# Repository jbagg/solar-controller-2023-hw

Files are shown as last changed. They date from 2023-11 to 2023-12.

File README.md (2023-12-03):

This is a differential temperature controller with 8 temperature sensor inputs, 4 digital inputs and 8 opto coupled solid state relay outputs.  The controller is compatible with the [LMT01](https://www.ti.com/product/LMT01) temperature sensor.  Each temperature sensor is connected to the controller with one pair of a cat 5 or 6 cable.  The temperature sensor uses the same 2 wires for both power and signaling.  Each temperature sensor has a max length of 45 meters.

The LMT01 is an ideal temperature sensor for differential temperature controllers as it

* uses digital signaling so no noise is added to the measurement over the cable back to the controller.
* allows for differential signaling for long cables.
* needs only 2 wires (twisted pair) per sensor.  Power and signaling is done over the same wires.

### Sensor Operation

The LMT01 uses a Pulse Train Interface to communicate the temperature where the number of output pulses is proportional to temperature.  The 1 or 0, high or low of each pulse is communicated by switching the device current consumption between two values, aprox 34uA and 125uA.

The controller measures each LMT01 sensor one at a time via U1, ADG707 differential 8-to-1 multiplexer.  When a sensor is muxed, its positive pin is connected to a 3.3kΩ pull up (R17) and its negative pin is connected to a 3.3kΩ pull down (R18).  Each resistor sees about a 300mV change in voltage between the pulse’s high / low 34uA and 125uA change in device current.  When R17’s change is positive, R18’s is negative.  These signal pulses are AC coupled to a differential op-amp circuit (U3A) via C20 and C39.  680pF was chosen to be about half the time constant for the 88Khz pulse.

1 / 88Khz = 11.4uS.  680pF * 10K = 6.8uS.

C20 and C39 must charge before they pass the pulses.  Too large a value looses pulses at the beginning.  680pF was measured to loose about 1 pulse, or about 0.1 C.

The differential op-amp circuit separates common noise from the differential signal that the twisted pair has picked up from noise sources over it’s length.  The differential op-amp circuit has gain to compensate for the signal loss in the cable.  The differential op-amp circuit has a gain of about 5 which is the max value not to saturate the strongest signal, a sensor connected directly to the controller without a length of wire.

[300mV - (-300mV)] * 5 <br>
= 600mV * 5 <br>
= 3v  (U1 has 3.3v supply)

The gain can be increased to just below the saturation point of the shortest cable.  C1 and C2 filter high frequency noise.  The output of the differential op-amp circuit is feed to a comparator with hysteresis (U3B).

The comparator has a hysteresis of 314mV.  A cat-5 twisted pair of up to 45 meters still had enough margin above the 314mV hysteresis for reliable operation.  The output of the comparator is feed to the microcontroller’s external timer counter clock input.

The microcontroller’s external timer counter clock (TCLK0) input feeds both TC0 and TC1 timer counters in the SAM4S2 mcu.  TC0 uses TCLK0 as a clock source and thus counts the pulses from the sensor.  The value of TC0 can be read and converted to a temperature.  TC1 is used to trigger when the LMT01 has finished sending pulses.  TC1 is clocked from the main mcu clock.  TC1 is configured so that its value is reset each time there is an edge on TCLK0.  TC1 compare C register is configured to a value about 2x the normal pulse period of the LMT01.  Each pulse from the LMT01 resets the count in TC1.  When the LMT01 stops sending pulses, TC1’s value grows to match compare C register which triggers an interrupt for the software to read TC0 and then change the mux to the next sensor and start all over again.

### Opto Coupler Ouptputs

Opto coupler AQH0213 is used to drive the coil of a relay that controls the load.  The AQH0213 is apart of a family of opto couplers with the same footprint.  The appropriate opto coupler can be chosen to match the voltage and current requirements of the specific relay for the application.

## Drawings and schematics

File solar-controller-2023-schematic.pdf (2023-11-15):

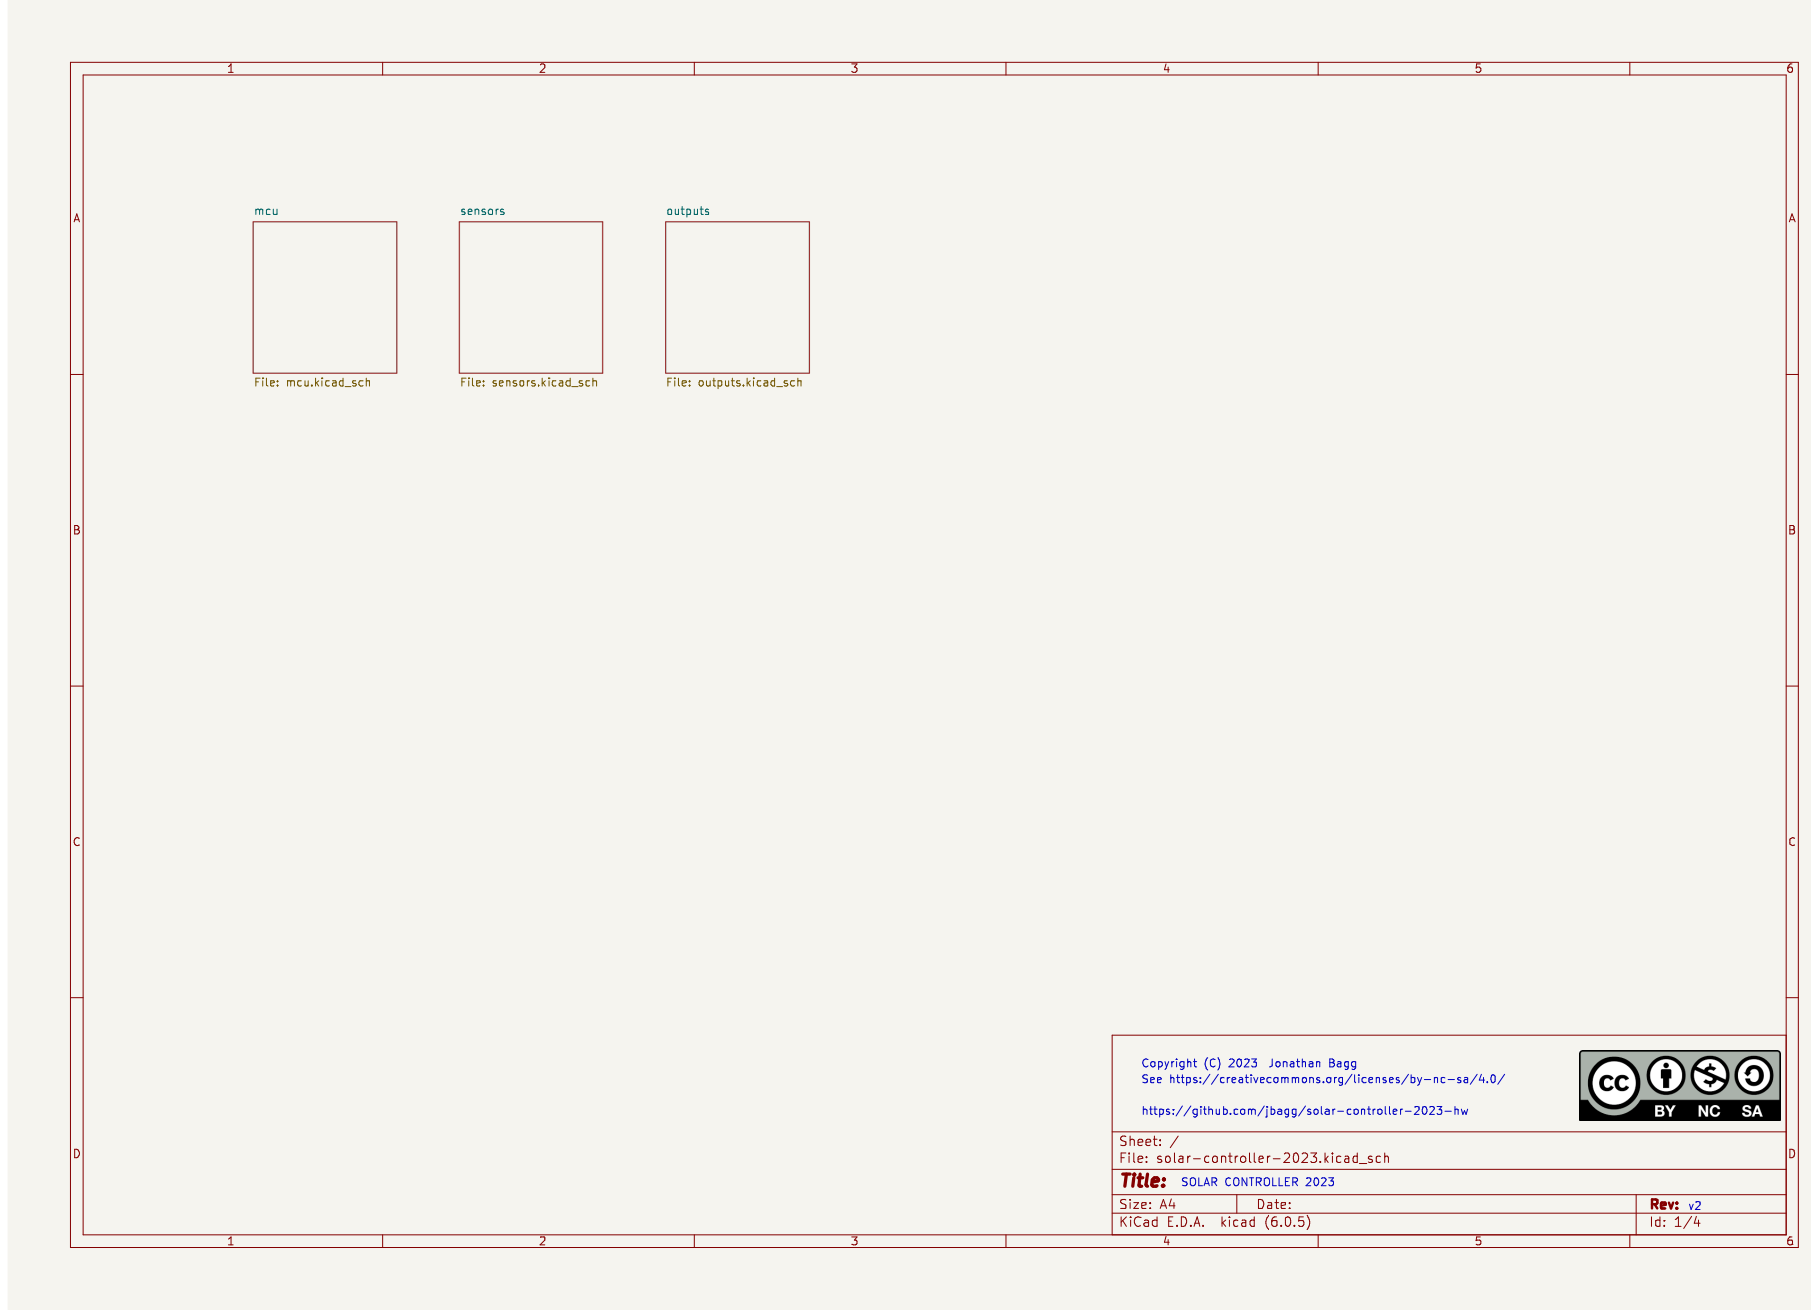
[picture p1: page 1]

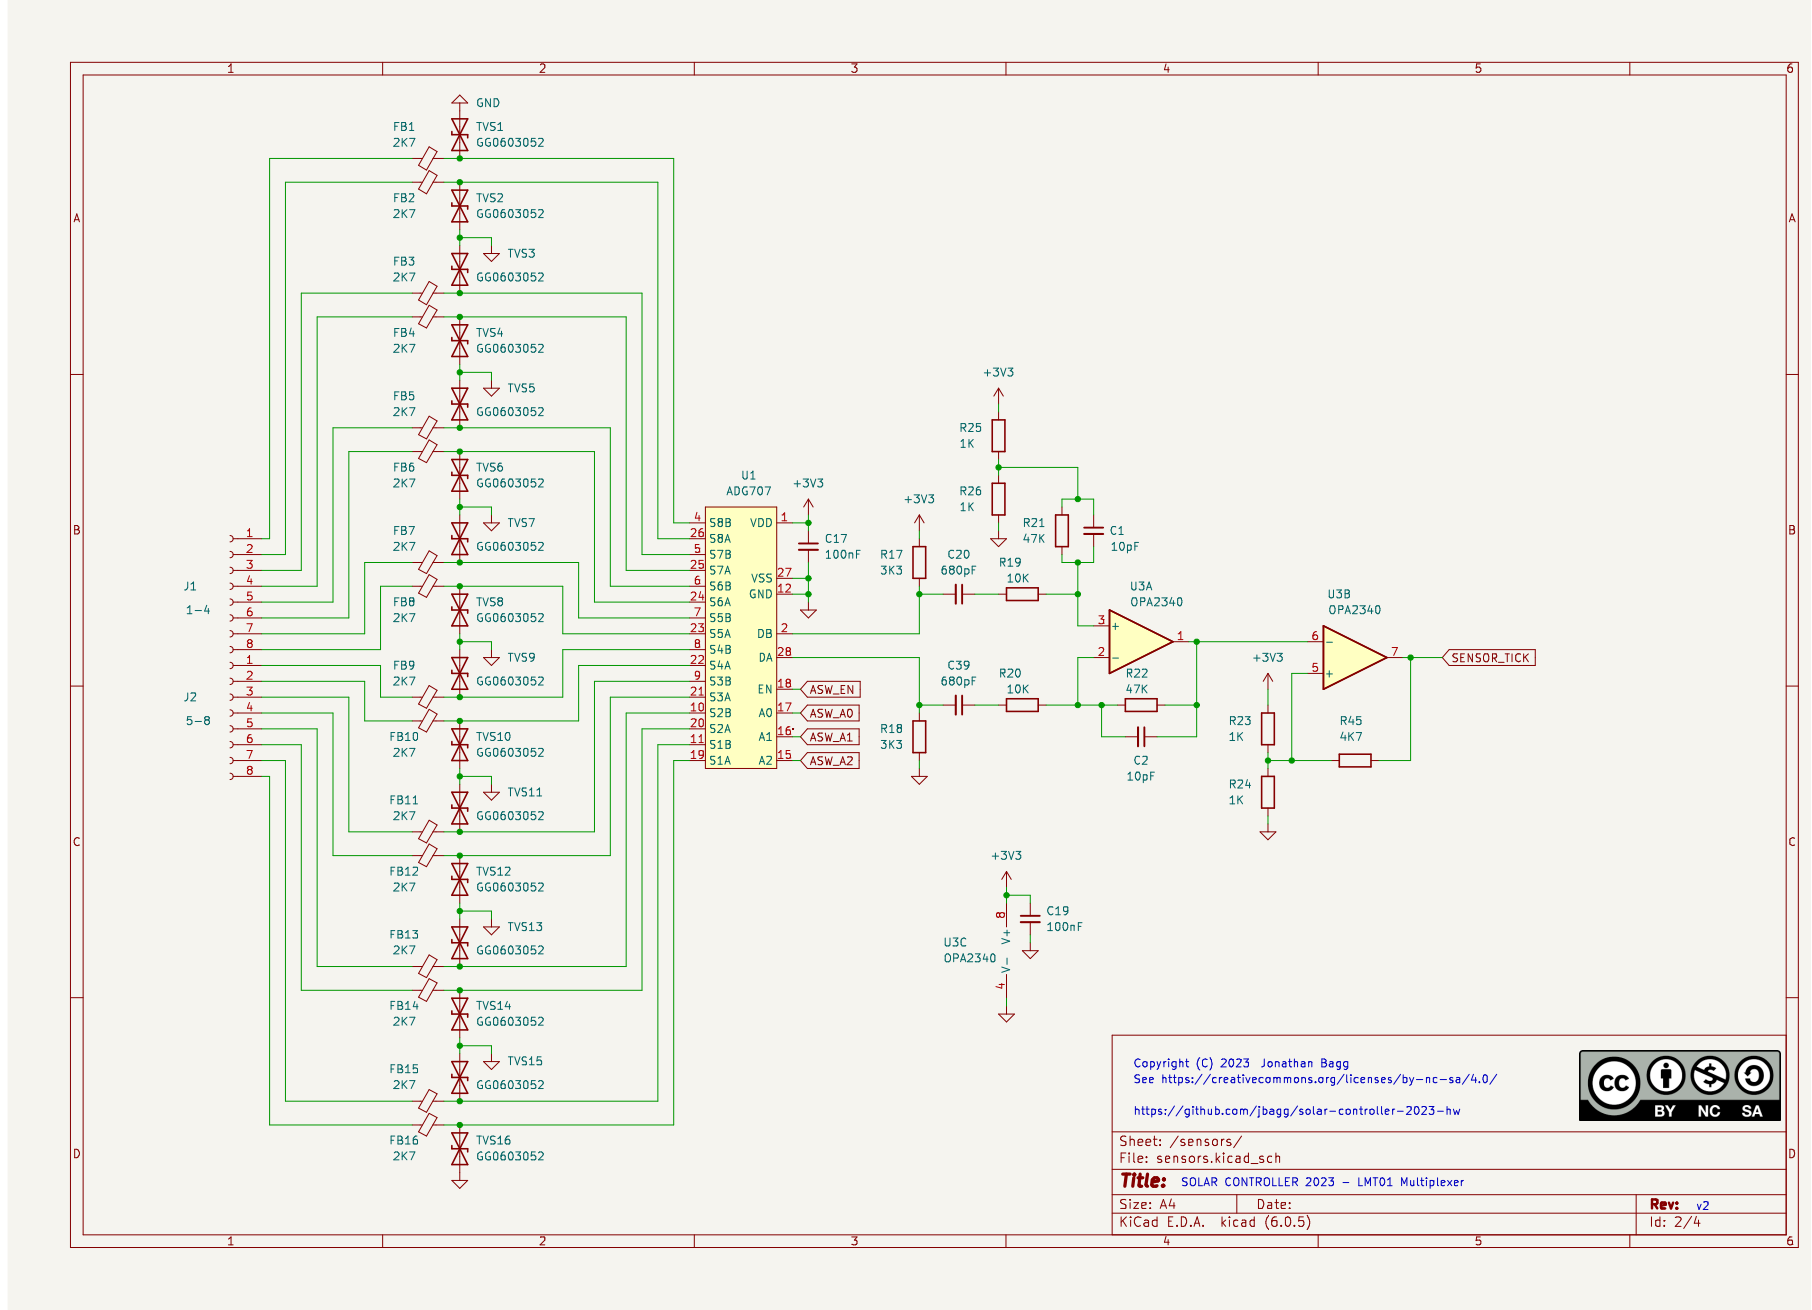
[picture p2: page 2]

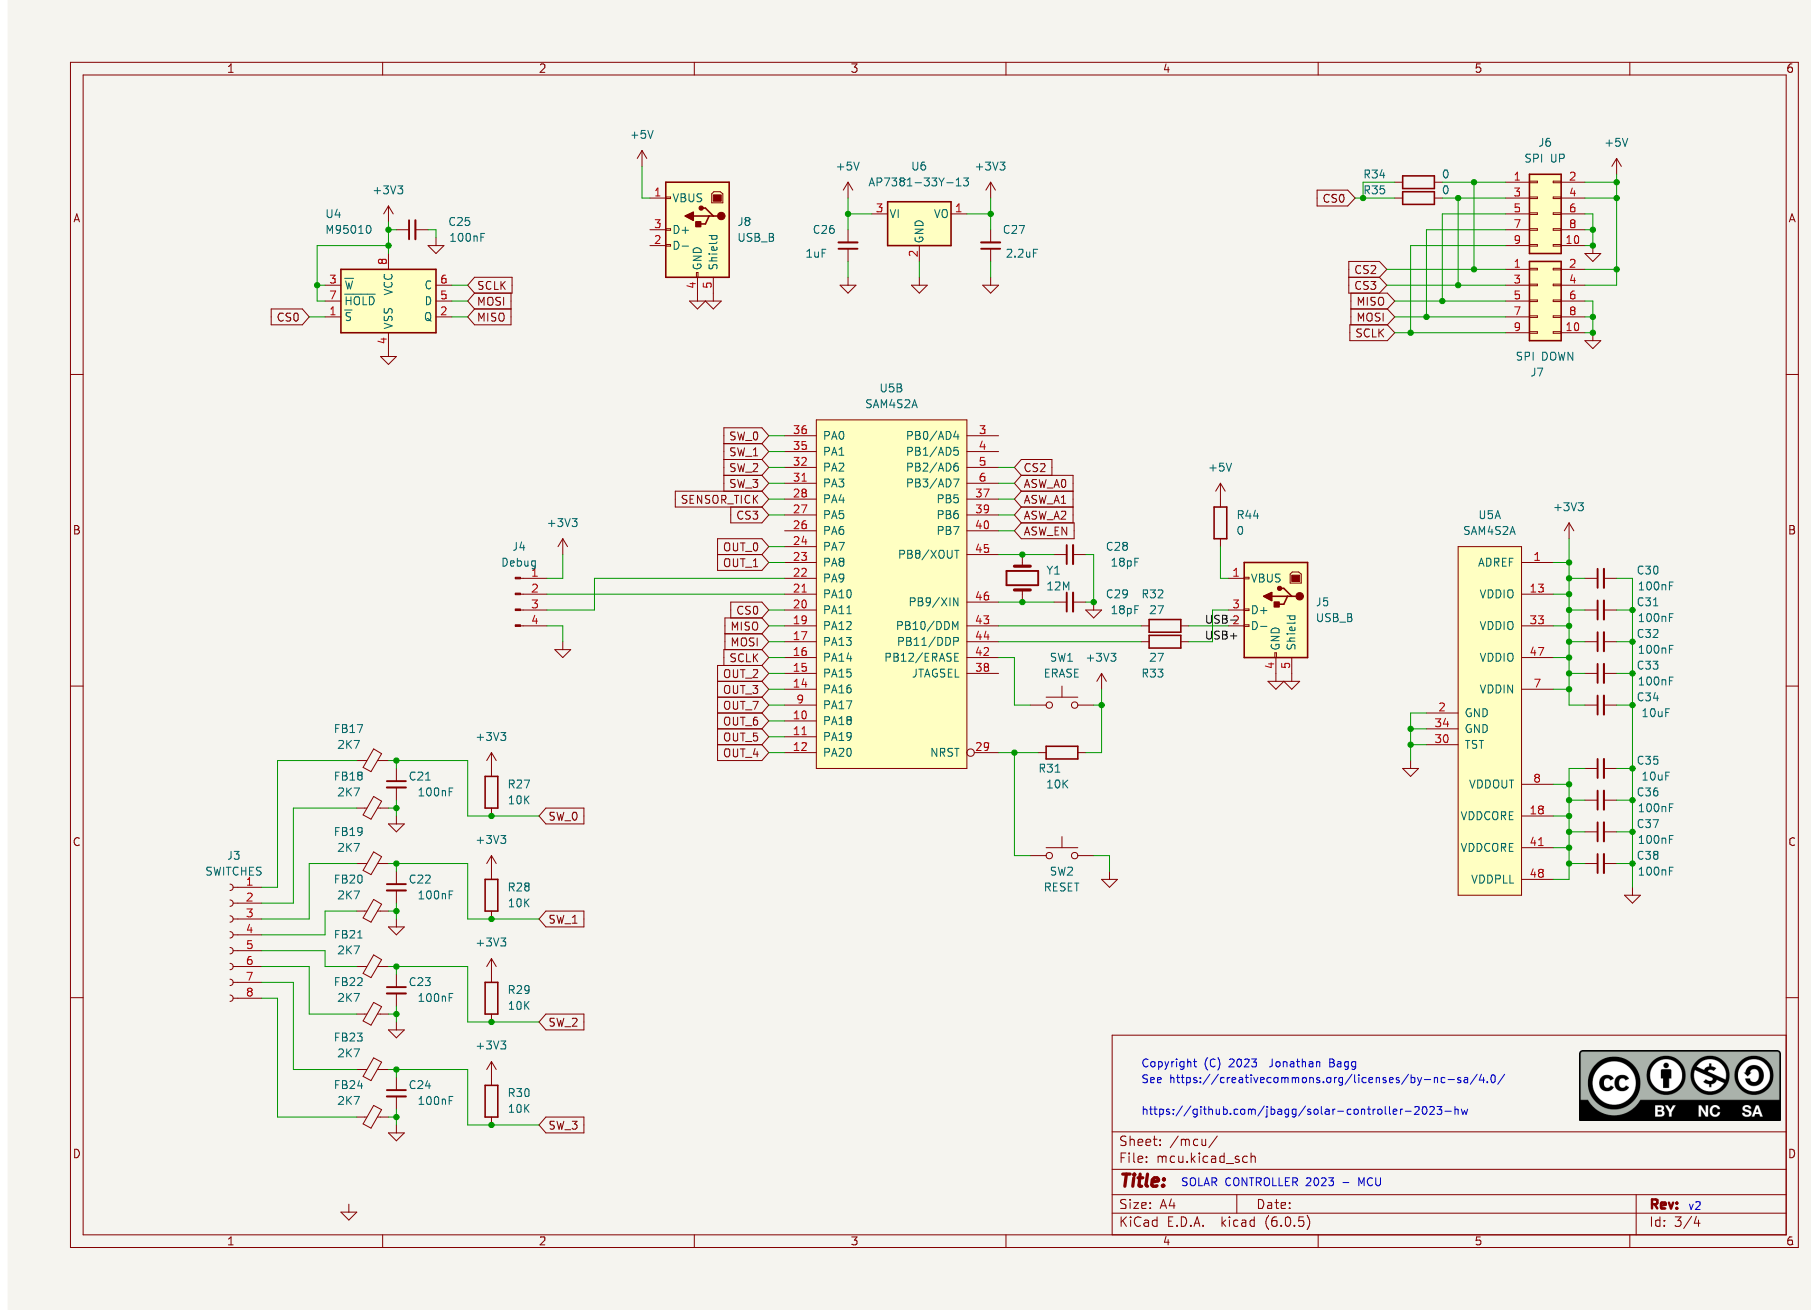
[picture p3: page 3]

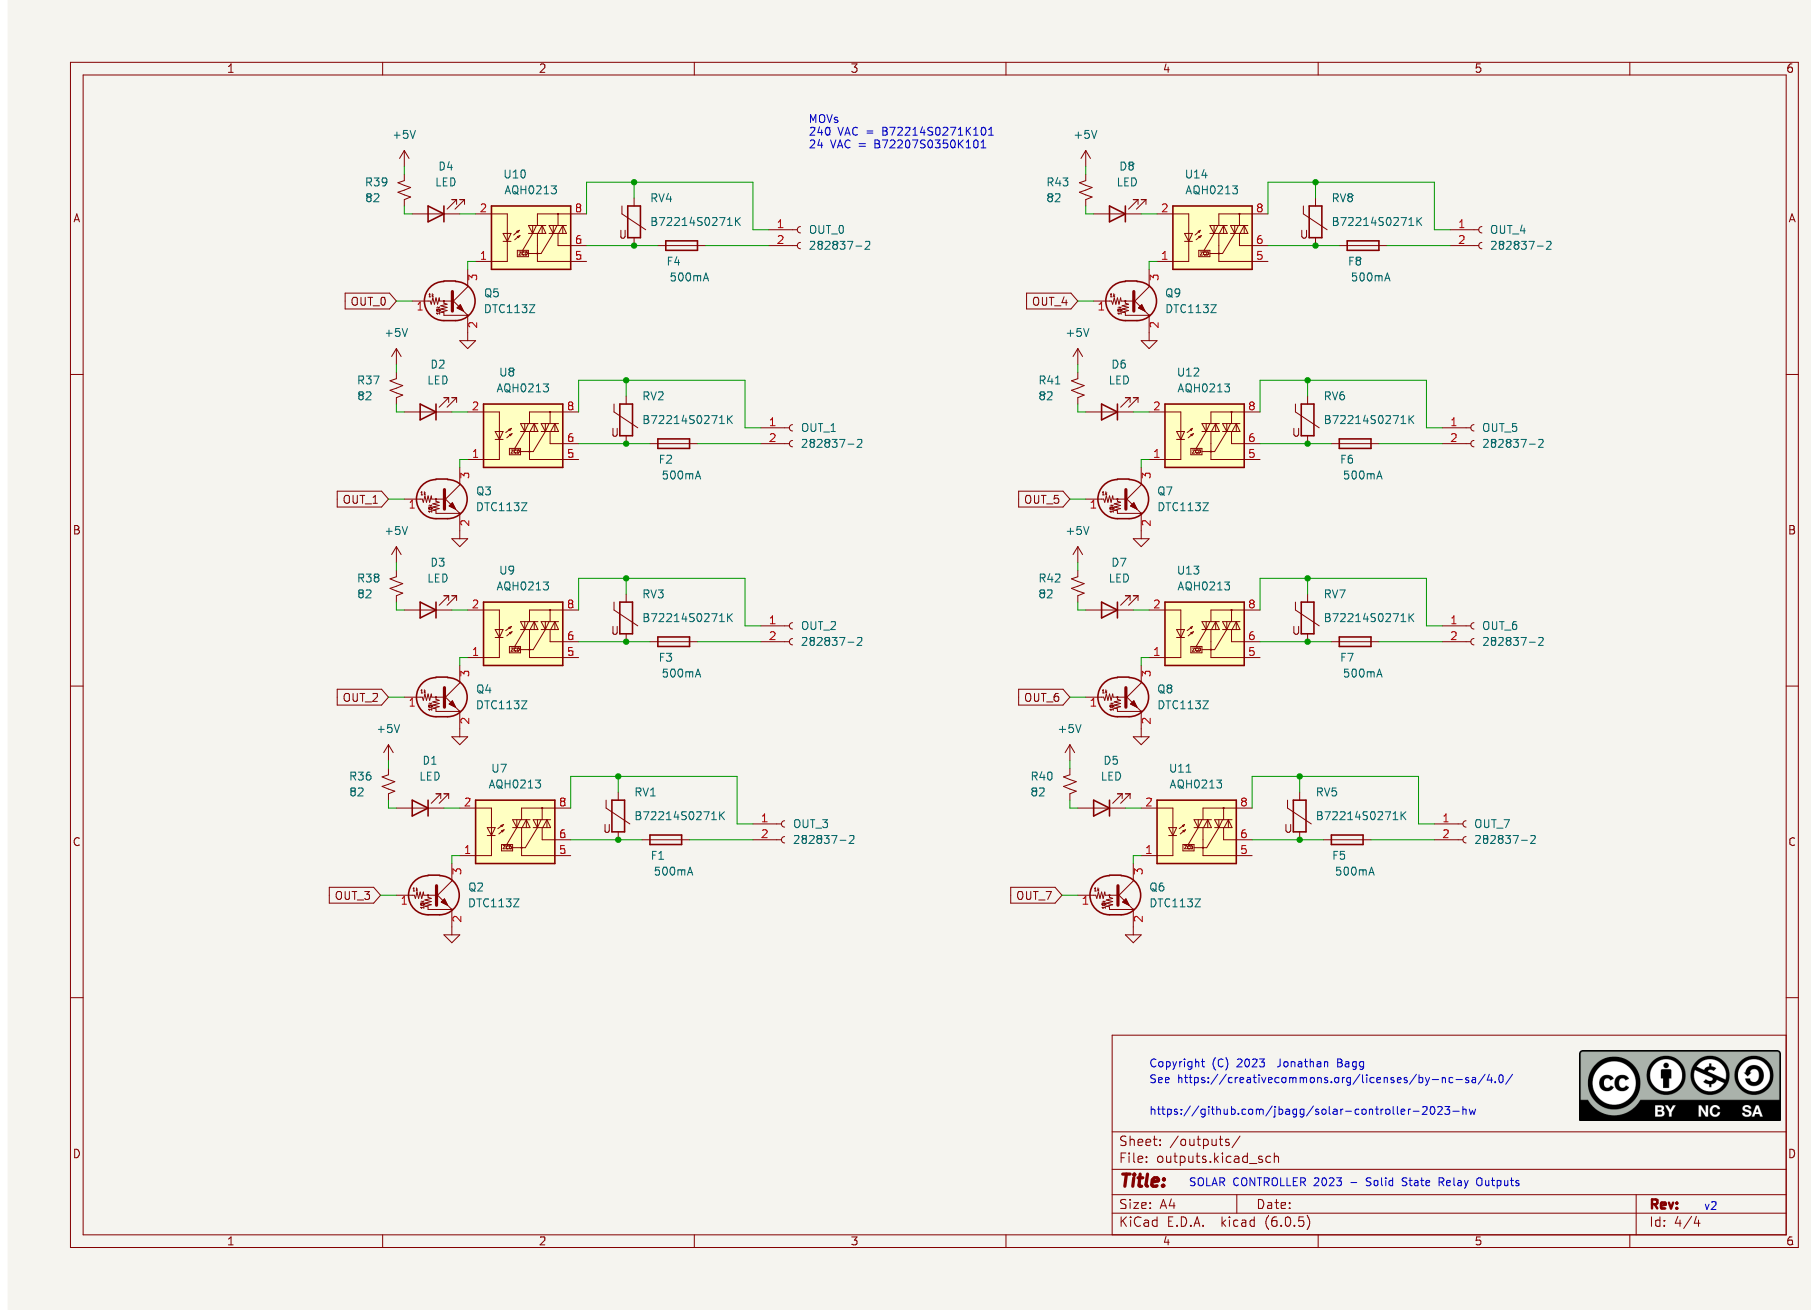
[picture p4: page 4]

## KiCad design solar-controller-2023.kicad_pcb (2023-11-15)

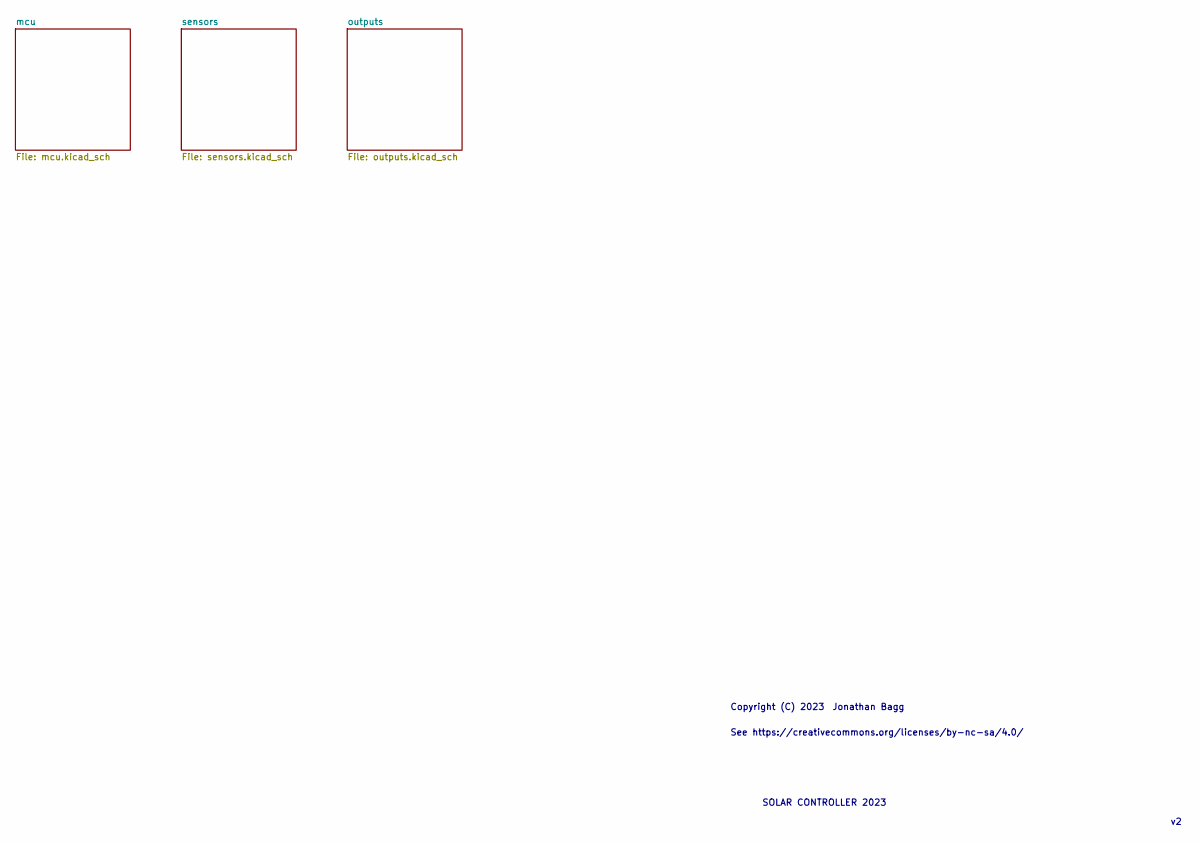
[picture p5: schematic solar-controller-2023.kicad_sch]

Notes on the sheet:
Copyright (C) 2023
See https://creativecommons.org/licenses/by-nc-sa/4.0/
Jonathan Bagg
SOLAR CONTROLLER 2023

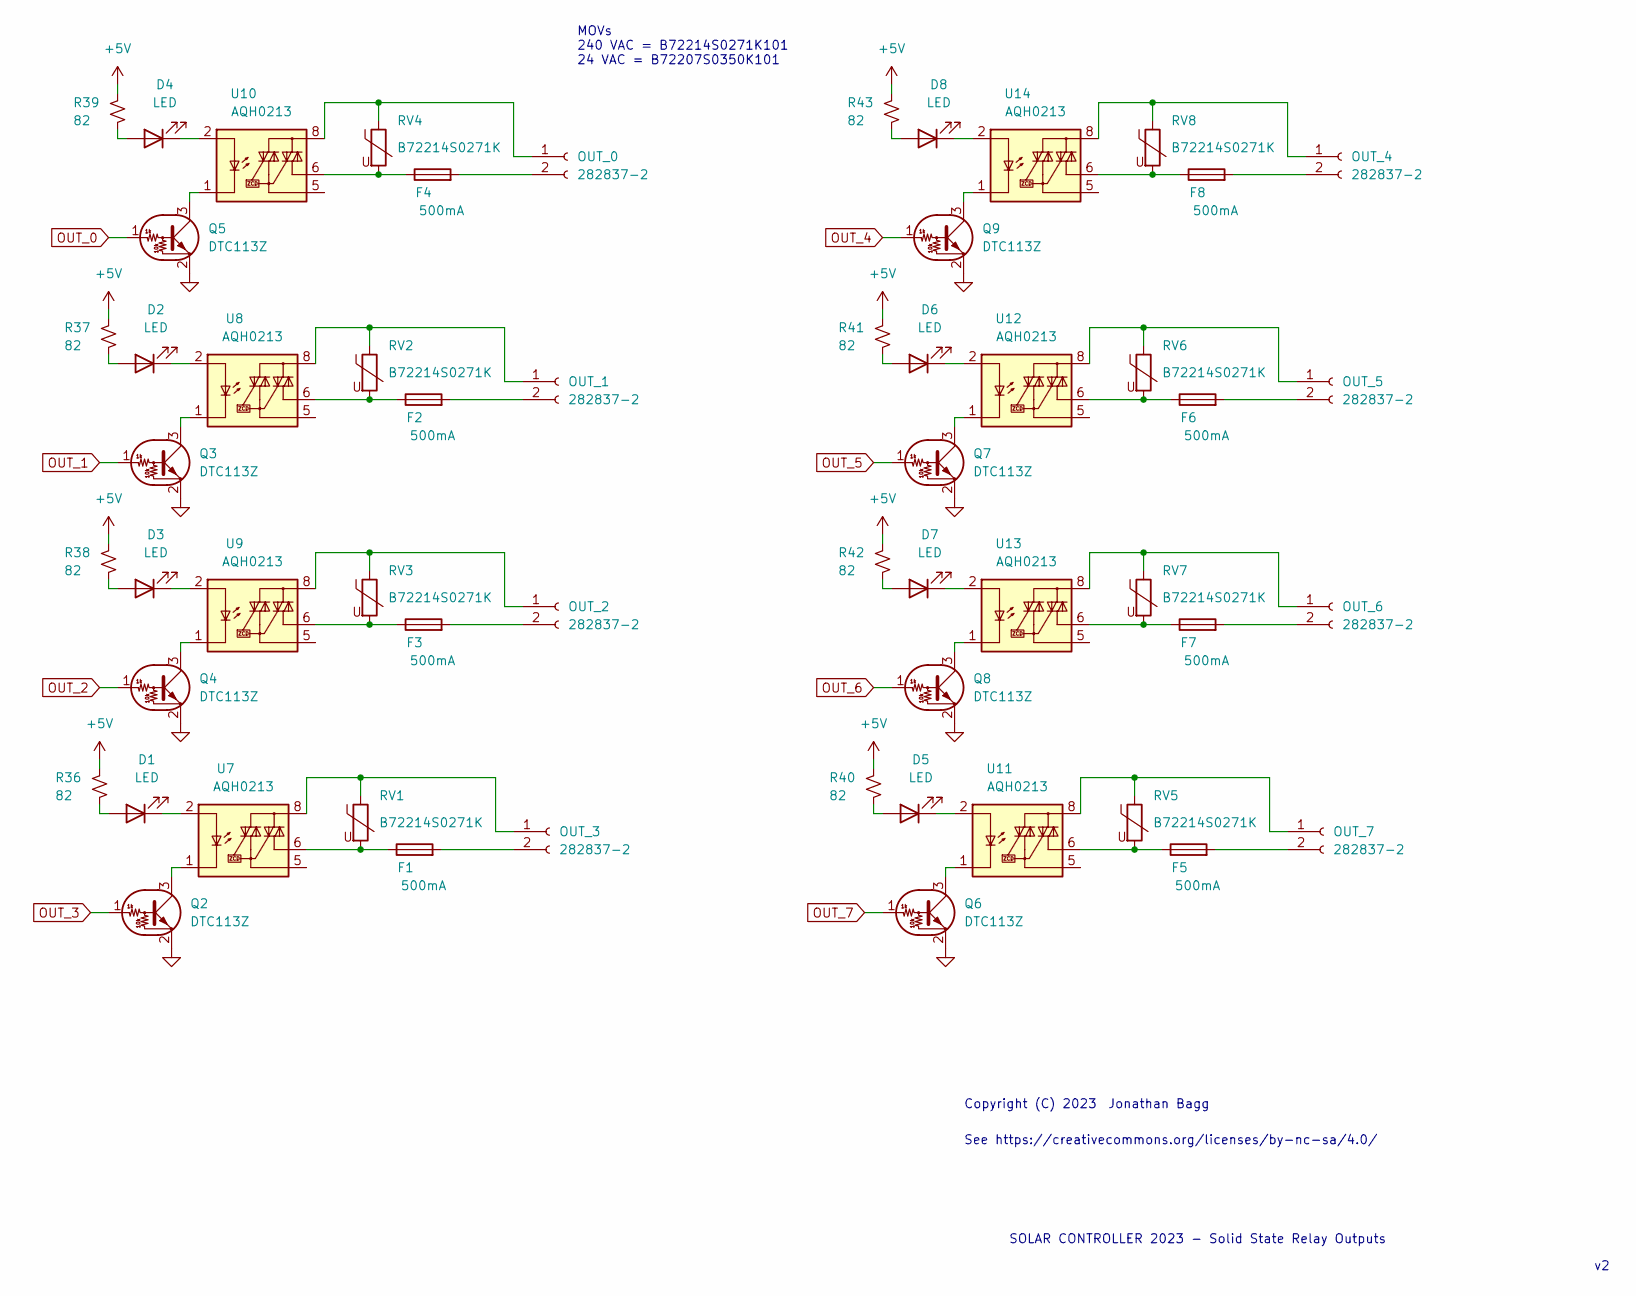
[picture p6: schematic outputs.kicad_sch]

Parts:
D1, D2, D3, D4, D5, D6, D7, D8: LED; D_0603_1608Metric_Pad1.05x0.95mm_HandSolder; Digikey 160-1436-1-ND
F1, F2, F3, F4, F5, F6, F7, F8: 500mA; C_Disc_D8.0mm_W5.0mm_P5.00mm; Digikey 507-1924-1-ND
OUT_0, OUT_1, OUT_2, OUT_3, OUT_4, OUT_5, OUT_6, OUT_7: 282837-2; 282837-2_TYC; Digikey A113320-ND
Q2, Q3, Q4, Q5, Q6, Q7, Q8, Q9: DTC113Z; SOT-23
R36, R37, R38, R39, R40, R41, R42, R43: 82; R_0805_2012Metric_Pad1.20x1.40mm_HandSolder; Digikey RMCF0805FT82R0CT-ND
RV1, RV2, RV3, RV4, RV5, RV6, RV7, RV8: B72214S0271K; C_Rect_L9.0mm_W2.5mm_P7.50mm_MKT; Digikey 495-1412-ND
U7, U8, U9, U10, U11, U12, U13, U14: AQH0213; DIP-8-N7_W7.62mm; Digikey 255-5987-ND

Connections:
+5V: R36.1, R37.1, R38.1, R39.1, R40.1, R41.1, R42.1, R43.1; also elsewhere on the board
GND: Q2.2 (E), Q3.2 (E), Q4.2 (E), Q5.2 (E), Q6.2 (E), Q7.2 (E), Q8.2 (E), Q9.2 (E); also elsewhere on the board
unnamed: D1.1 (K), U7.2
unnamed: D1.2 (A), R36.2
unnamed: D2.1 (K), U8.2
unnamed: D2.2 (A), R37.2
unnamed: D3.1 (K), U9.2
unnamed: D3.2 (A), R38.2
unnamed: D4.1 (K), U10.2
unnamed: D4.2 (A), R39.2
unnamed: D5.1 (K), U11.2
unnamed: D5.2 (A), R40.2
unnamed: D6.1 (K), U12.2
unnamed: D6.2 (A), R41.2
unnamed: D7.1 (K), U13.2
unnamed: D7.2 (A), R42.2
unnamed: D8.1 (K), U14.2
unnamed: D8.2 (A), R43.2
unnamed: F1.1, RV1.2, U7.6
unnamed: F1.2, OUT_3.2
unnamed: F2.1, RV2.2, U8.6
unnamed: F2.2, OUT_1.2
unnamed: F3.1, RV3.2, U9.6
unnamed: F3.2, OUT_2.2
unnamed: F4.1, RV4.2, U10.6
unnamed: F4.2, OUT_0.2
unnamed: F5.1, RV5.2, U11.6
unnamed: F5.2, OUT_7.2
unnamed: F6.1, RV6.2, U12.6
unnamed: F6.2, OUT_5.2
unnamed: F7.1, RV7.2, U13.6
unnamed: F7.2, OUT_6.2
unnamed: F8.1, RV8.2, U14.6
unnamed: F8.2, OUT_4.2
unnamed: OUT_0.1, RV4.1, U10.8
unnamed: OUT_1.1, RV2.1, U8.8
unnamed: OUT_2.1, RV3.1, U9.8
unnamed: OUT_3.1, RV1.1, U7.8
unnamed: OUT_4.1, RV8.1, U14.8
unnamed: OUT_5.1, RV6.1, U12.8
unnamed: OUT_6.1, RV7.1, U13.8
unnamed: OUT_7.1, RV5.1, U11.8
unnamed: Q2.3 (C), U7.1, U7.3, U7.4
unnamed: Q3.3 (C), U8.1, U8.3, U8.4
unnamed: Q4.3 (C), U9.1, U9.3, U9.4
unnamed: Q5.3 (C), U10.1, U10.3, U10.4
unnamed: Q6.3 (C), U11.1, U11.3, U11.4
unnamed: Q7.3 (C), U12.1, U12.3, U12.4
unnamed: Q8.3 (C), U13.1, U13.3, U13.4
unnamed: Q9.3 (C), U14.1, U14.3, U14.4
OUT_0: Q5.1 (B); also elsewhere on the board
OUT_1: Q3.1 (B); also elsewhere on the board
OUT_2: Q4.1 (B); also elsewhere on the board
OUT_3: Q2.1 (B); also elsewhere on the board
OUT_4: Q9.1 (B); also elsewhere on the board
OUT_5: Q7.1 (B); also elsewhere on the board
OUT_6: Q8.1 (B); also elsewhere on the board
OUT_7: Q6.1 (B); also elsewhere on the board

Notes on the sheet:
Copyright (C) 2023
See https://creativecommons.org/licenses/by-nc-sa/4.0/
MOVs 240 VAC = B72214S0271K101 24 VAC = B72207S0350K101
SOLAR CONTROLLER 2023 - Solid State Relay Outputs
Jonathan Bagg

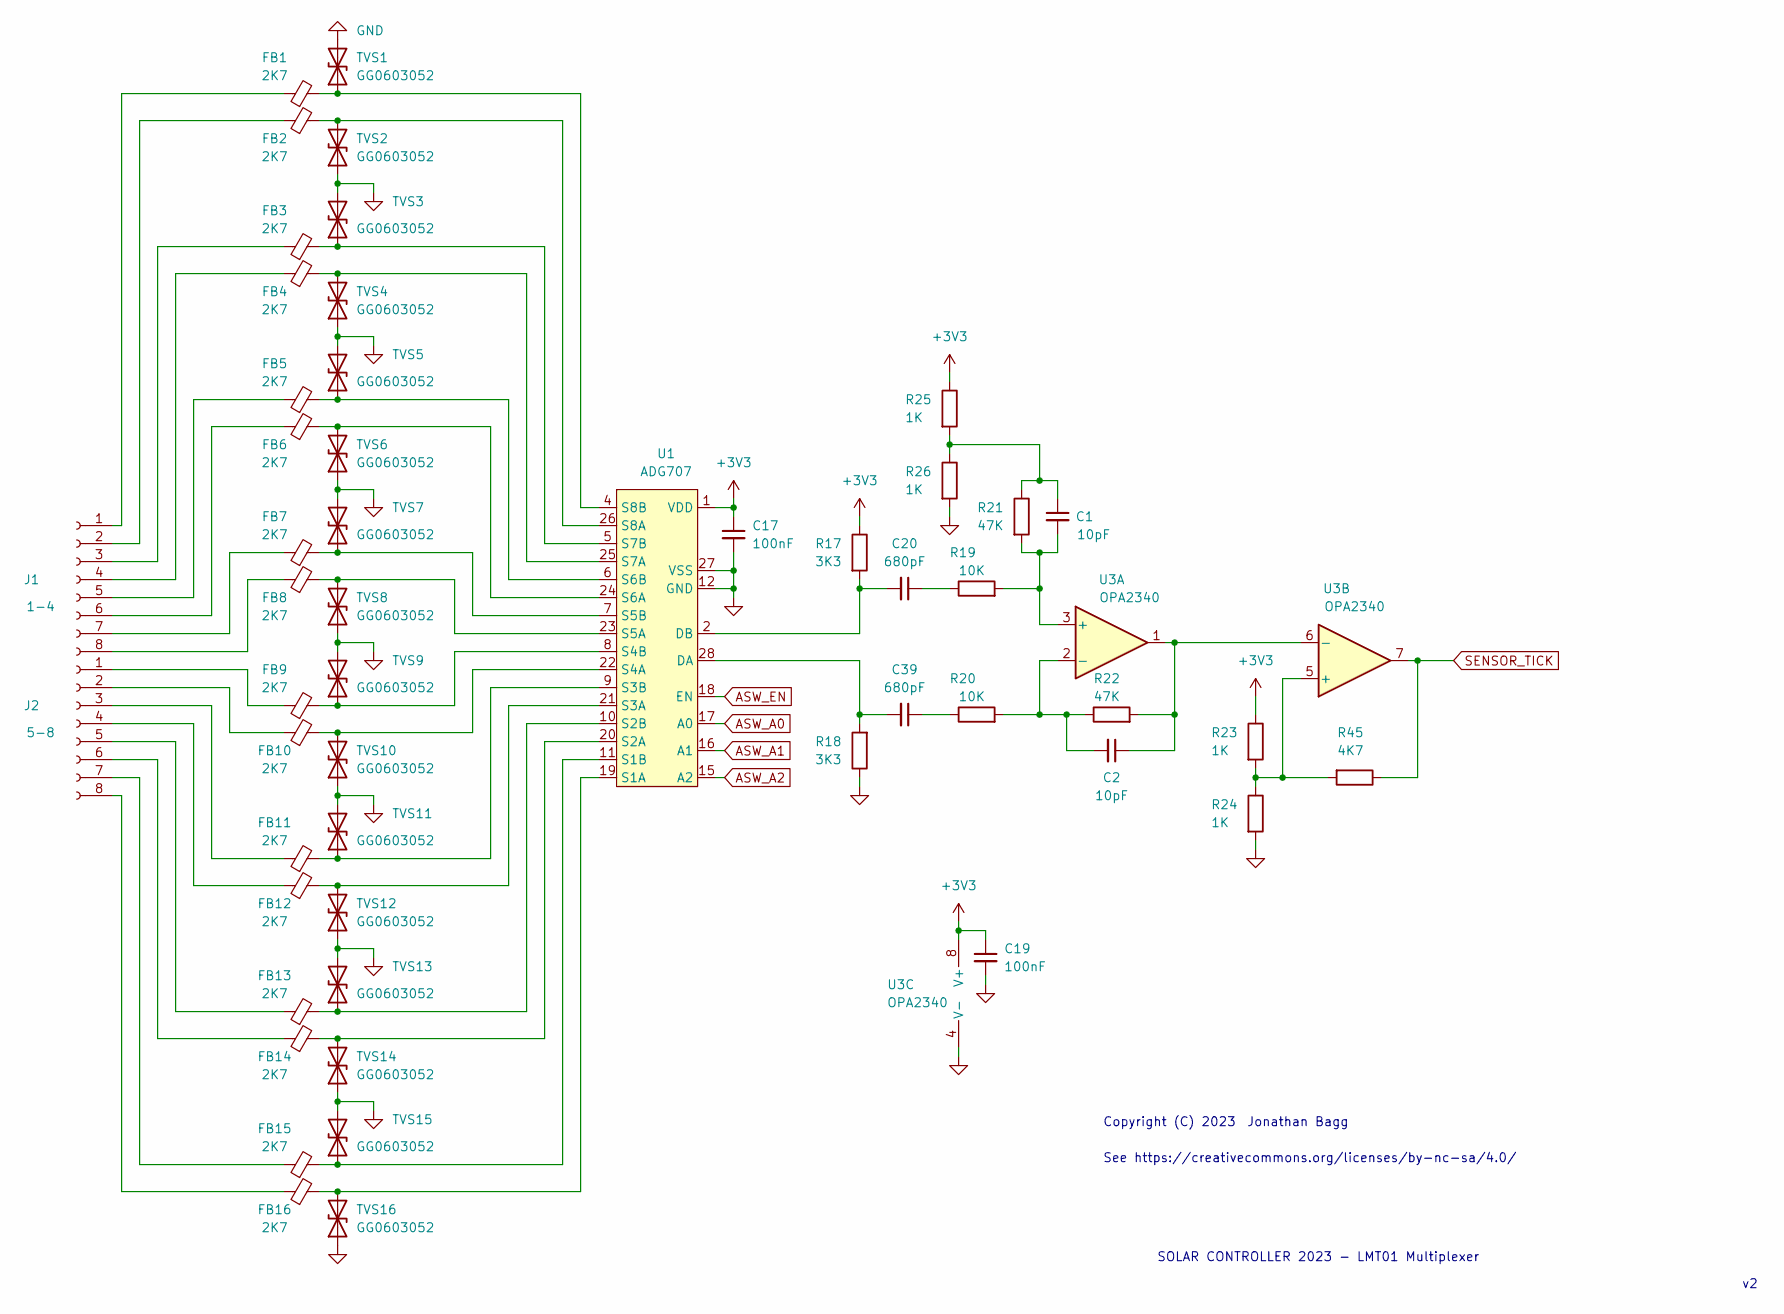
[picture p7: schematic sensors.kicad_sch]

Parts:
C1, C2: 10pF; C_0603_1608Metric_Pad1.08x0.95mm_HandSolder
C17, C19: 100nF; C_0603_1608Metric_Pad1.08x0.95mm_HandSolder
C20, C39: 680pF; C_0603_1608Metric_Pad1.08x0.95mm_HandSolder
FB1, FB2, FB3, FB4, FB5, FB6, FB7, FB8, FB9, FB10, FB11, FB12, FB13, FB14, FB15, FB16: 2K7; C_0603_1608Metric_Pad1.08x0.95mm_HandSolder
J1: 1-4; PinHeader_1x08_P2.54mm_Vertical; Digikey A98338-ND
J2: 5-8; PinHeader_1x08_P2.54mm_Vertical; Digikey A98338-ND
R17, R18: 3K3; R_0603_1608Metric_Pad0.98x0.95mm_HandSolder
R19, R20: 10K; R_0603_1608Metric_Pad0.98x0.95mm_HandSolder
R21, R22: 47K; R_0603_1608Metric_Pad0.98x0.95mm_HandSolder
R23, R24, R25, R26: 1K; R_0603_1608Metric_Pad0.98x0.95mm_HandSolder
R45: 4K7; R_0603_1608Metric_Pad0.98x0.95mm_HandSolder
TVS1, TVS2, TVS3, TVS4, TVS5, TVS6, TVS7, TVS8, TVS9, TVS10, TVS11, TVS12, TVS13, TVS14, TVS15, TVS16: GG0603052; D_0603_1608Metric_Pad1.05x0.95mm_HandSolder; Digikey 478-GG0603052R542PCT-ND
U1: ADG707; SSOP-28_5.3x10.2mm_P0.65mm
U3: OPA2340; SOP-8_3.9x4.9mm_P1.27mm; Digikey 296-26253-1-ND

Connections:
+3V3: C17.1, C19.1, R17.1, R23.1, R25.1, U1.1 (VDD), U3.8 (V+); also elsewhere on the board
ASW_A0: U1.17 (A0); also elsewhere on the board
ASW_A1: U1.16 (A1); also elsewhere on the board
ASW_A2: U1.15 (A2); also elsewhere on the board
ASW_EN: U1.18 (EN); also elsewhere on the board
GND: C17.2, C19.2, R18.1, R24.2, R26.2, TVS1.2 (A2), TVS2.1 (A1), TVS3.2 (A2), TVS4.1 (A1), TVS5.2 (A2), TVS6.1 (A1), TVS7.2 (A2), TVS8.1 (A1), TVS9.2 (A2), TVS10.1 (A1), TVS11.2 (A2), TVS12.1 (A1), TVS13.2 (A2), TVS14.1 (A1), TVS15.2 (A2), TVS16.1 (A1), U1.12 (GND), U1.27 (VSS), U3.4 (V-); also elsewhere on the board
unnamed: C20.1, R19.1
unnamed: C39.1, R20.1
unnamed: FB1.1, J1.1
unnamed: FB1.2, TVS1.1 (A1), U1.4 (S8B)
unnamed: FB2.1, J1.2
unnamed: FB2.2, TVS2.2 (A2), U1.26 (S8A)
unnamed: FB3.1, J1.3
unnamed: FB3.2, TVS3.1 (A1), U1.5 (S7B)
unnamed: FB4.1, J1.4
unnamed: FB4.2, TVS4.2 (A2), U1.25 (S7A)
unnamed: FB5.1, J1.5
unnamed: FB5.2, TVS5.1 (A1), U1.6 (S6B)
unnamed: FB6.1, J1.6
unnamed: FB6.2, TVS6.2 (A2), U1.24 (S6A)
unnamed: FB7.1, J1.7
unnamed: FB7.2, TVS7.1 (A1), U1.7 (S5B)
unnamed: FB8.1, J1.8
unnamed: FB8.2, TVS8.2 (A2), U1.23 (S5A)
unnamed: FB9.1, J2.1
unnamed: FB9.2, TVS9.1 (A1), U1.8 (S4B)
unnamed: FB10.1, J2.2
unnamed: FB10.2, TVS10.2 (A2), U1.22 (S4A)
unnamed: FB11.1, J2.3
unnamed: FB11.2, TVS11.1 (A1), U1.9 (S3B)
unnamed: FB12.1, J2.4
unnamed: FB12.2, TVS12.2 (A2), U1.21 (S3A)
unnamed: FB13.1, J2.5
unnamed: FB13.2, TVS13.1 (A1), U1.10 (S2B)
unnamed: FB14.1, J2.6
unnamed: FB14.2, TVS14.2 (A2), U1.20 (S2A)
unnamed: FB15.1, J2.7
unnamed: FB15.2, TVS15.1 (A1), U1.11 (S1B)
unnamed: FB16.1, J2.8
unnamed: FB16.2, TVS16.2 (A2), U1.19 (S1A)
unnamed: C20.2, R17.2, U1.2 (DB)
unnamed: C39.2, R18.2, U1.28 (DA)
unnamed: C1.2, R19.2, R21.2, U3.3 (+)
unnamed: C2.2, R20.2, R22.1, U3.2 (-)
unnamed: C2.1, R22.2, U3.1, U3.6 (-)
unnamed: R23.2, R24.1, R45.2, U3.5 (+)
unnamed: C1.1, R21.1, R25.2, R26.1
SENSOR_TICK: R45.1, U3.7; also elsewhere on the board

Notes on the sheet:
See https://creativecommons.org/licenses/by-nc-sa/4.0/
Copyright (C) 2023
SOLAR CONTROLLER 2023 - LMT01 Multiplexer
Jonathan Bagg

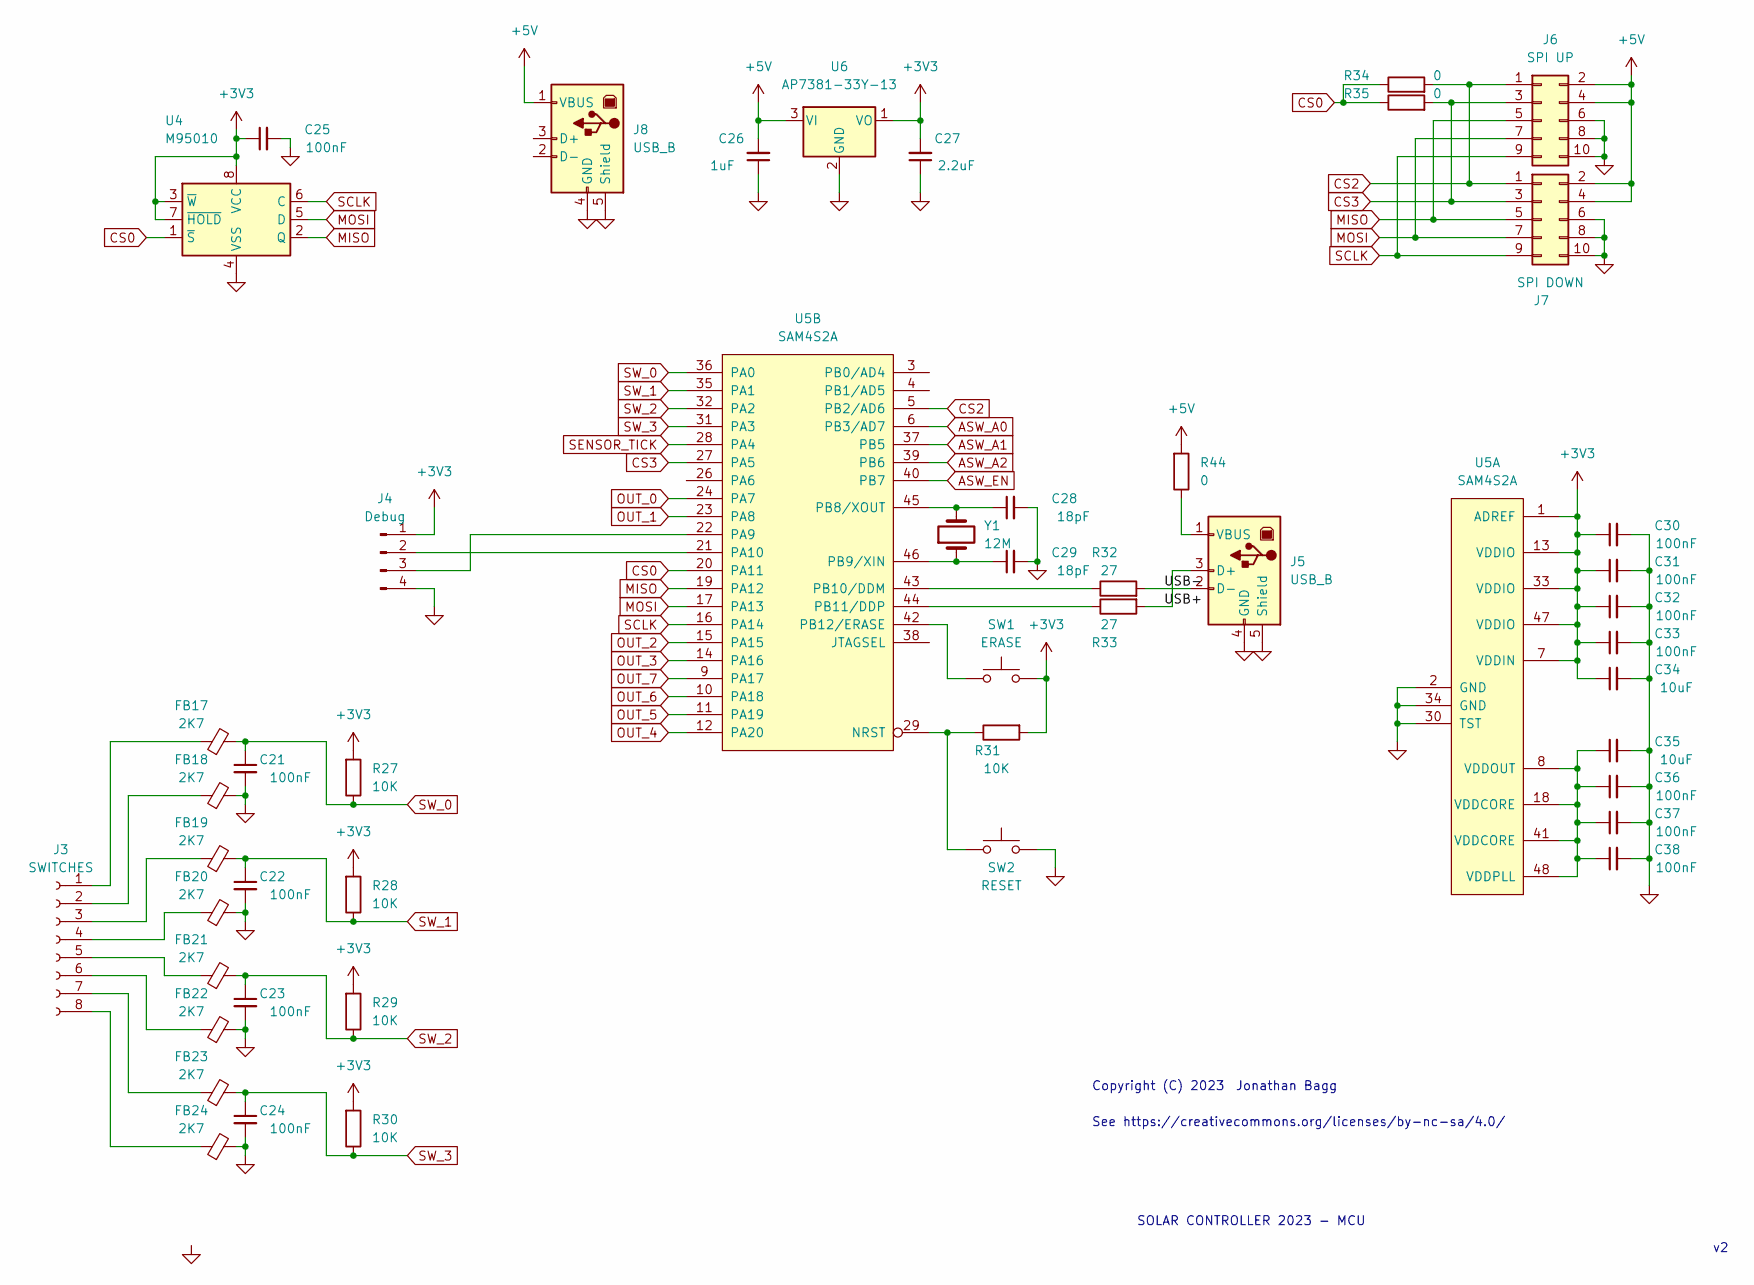
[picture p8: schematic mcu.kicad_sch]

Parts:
C21, C22, C23, C24, C25, C30, C31, C32, C33, C36, C37, C38: 100nF; C_0603_1608Metric_Pad1.08x0.95mm_HandSolder
C26: 1uF; C_0805_2012Metric_Pad1.18x1.45mm_HandSolder; Digikey 490-10494-1-ND
C27: 2.2uF; C_0805_2012Metric_Pad1.18x1.45mm_HandSolder; Digikey 587-EMF212B7225KGHTCT-ND
C28, C29: 18pF; C_0603_1608Metric_Pad1.08x0.95mm_HandSolder
C34, C35: 10uF; C_0805_2012Metric_Pad1.18x1.45mm_HandSolder
FB17, FB18, FB19, FB20, FB21, FB22, FB23, FB24: 2K7; C_0603_1608Metric_Pad1.08x0.95mm_HandSolder
J3: SWITCHES; PinHeader_1x08_P2.54mm_Vertical; Digikey A98338-ND
J4: Debug; PinHeader_1x04_P2.54mm_Vertical
J5, J8: USB_B; USB_Micro-B_Amphenol_10118194_Horizontal; Digikey 609-4618-1-ND
J6: SPI UP; PinHeader_2x05_P2.54mm_Vertical; Digikey 732-2865-ND
J7: SPI DOWN; PinHeader_2x05_P2.54mm_Vertical; Digikey 732-2676-ND
R27, R28, R29, R30, R31: 10K; R_0603_1608Metric_Pad0.98x0.95mm_HandSolder
R32, R33: 27; R_0603_1608Metric_Pad0.98x0.95mm_HandSolder
R34, R35, R44: 0; R_0603_1608Metric_Pad0.98x0.95mm_HandSolder
SW1: ERASE; SW_Push_1P1T_NO_6x6mm_H9.5mm; Digikey 2223-TS04-66-50-BK-260-SMT-ND
SW2: RESET; SW_Push_1P1T_NO_6x6mm_H9.5mm; Digikey 2223-TS04-66-50-BK-260-SMT-ND
U4: M95010; SOIC-8_3.9x4.9mm_P1.27mm; Digikey 497-8672-1-ND
U5: SAM4S2A; LQFP-48_7x7mm_P0.5mm; Digikey ATSAM4S2AB-ANR-CT-ND
U6: AP7381-33Y-13; SOT-89-3-JB; Digikey AP7381-33Y-13DICT-ND
Y1: 12M; Crystal_HC49-4H_Vertical

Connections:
+3V3: C25.1, C27.2, C30.1, C31.1, C32.1, C33.1, C34.1, J4.1, R27.2, R28.2, R29.2, R30.2, R31.2, SW1.2, U4.3 (~W), U4.7 (~HOLD), U4.8 (VCC), U5.1 (ADREF), U5.7 (VDDIN), U5.13 (VDDIO), U5.33 (VDDIO), U5.47 (VDDIO), U6.1 (VO); also elsewhere on the board
+5V: C26.2, J6.2, J6.4, J7.2, J7.4, J8.1 (VBUS), R44.2, U6.3 (VI); also elsewhere on the board
/mcu/USB+: J5.3 (D+), R33.2
/mcu/USB-: J5.2 (D-), R32.2
ASW_A0: U5.6 (PB3/AD7); also elsewhere on the board
ASW_A1: U5.37 (PB5); also elsewhere on the board
ASW_A2: U5.39 (PB6); also elsewhere on the board
ASW_EN: U5.40 (PB7); also elsewhere on the board
CS0: R34.1, R35.1, U4.1 (~S), U5.20 (PA11)
CS2: J6.1, J7.1, R34.2, U5.5 (PB2/AD6)
CS3: J6.3, J7.3, R35.2, U5.27 (PA5)
GND: C21.2, C22.2, C23.2, C24.2, C25.2, C26.1, C27.1, C28.2, C29.2, C30.2, C31.2, C32.2, C33.2, C34.2, C35.2, C36.2, C37.2, C38.2, FB18.2, FB20.2, FB22.2, FB24.2, J4.4, J5.4 (GND), J5.5 (Shield), J6.6, J6.8, J6.10, J7.6, J7.8, J7.10, J8.4 (GND), J8.5 (Shield), SW2.2, U4.4 (VSS), U5.2 (GND), U5.30 (TST), U5.34 (GND), U6.2 (GND); also elsewhere on the board
MISO: J6.5, J7.5, U4.2 (Q), U5.19 (PA12)
MOSI: J6.7, J7.7, U4.5 (D), U5.17 (PA13)
unnamed: C28.1, U5.45 (PB8/XOUT), Y1.2
unnamed: C29.1, U5.46 (PB9/XIN), Y1.1
unnamed: C35.1, C36.1, C37.1, C38.1, U5.8 (VDDOUT), U5.18 (VDDCORE), U5.41 (VDDCORE), U5.48 (VDDPLL)
unnamed: FB17.1, J3.1
unnamed: FB18.1, J3.2
unnamed: FB19.1, J3.3
unnamed: FB20.1, J3.4
unnamed: FB21.1, J3.5
unnamed: FB22.1, J3.6
unnamed: FB23.1, J3.7
unnamed: FB24.1, J3.8
unnamed: J4.2, U5.21 (PA10)
unnamed: J4.3, U5.22 (PA9)
unnamed: J5.1 (VBUS), R44.1
unnamed: R31.1, SW2.1, U5.29 (NRST)
unnamed: R32.1, U5.43 (PB10/DDM)
unnamed: R33.1, U5.44 (PB11/DDP)
unnamed: SW1.1, U5.42 (PB12/ERASE)
OUT_0: U5.24 (PA7); also elsewhere on the board
OUT_1: U5.23 (PA8); also elsewhere on the board
OUT_2: U5.15 (PA15); also elsewhere on the board
OUT_3: U5.14 (PA16); also elsewhere on the board
OUT_4: U5.12 (PA20); also elsewhere on the board
OUT_5: U5.11 (PA19); also elsewhere on the board
OUT_6: U5.10 (PA18); also elsewhere on the board
OUT_7: U5.9 (PA17); also elsewhere on the board
SCLK: J6.9, J7.9, U4.6 (C), U5.16 (PA14)
SENSOR_TICK: U5.28 (PA4); also elsewhere on the board
SW_0: C21.1, FB17.2, R27.1, U5.36 (PA0)
SW_1: C22.1, FB19.2, R28.1, U5.35 (PA1)
SW_2: C23.1, FB21.2, R29.1, U5.32 (PA2)
SW_3: C24.1, FB23.2, R30.1, U5.31 (PA3)

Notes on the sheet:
See https://creativecommons.org/licenses/by-nc-sa/4.0/
Jonathan Bagg
SOLAR CONTROLLER 2023 - MCU
Copyright (C) 2023

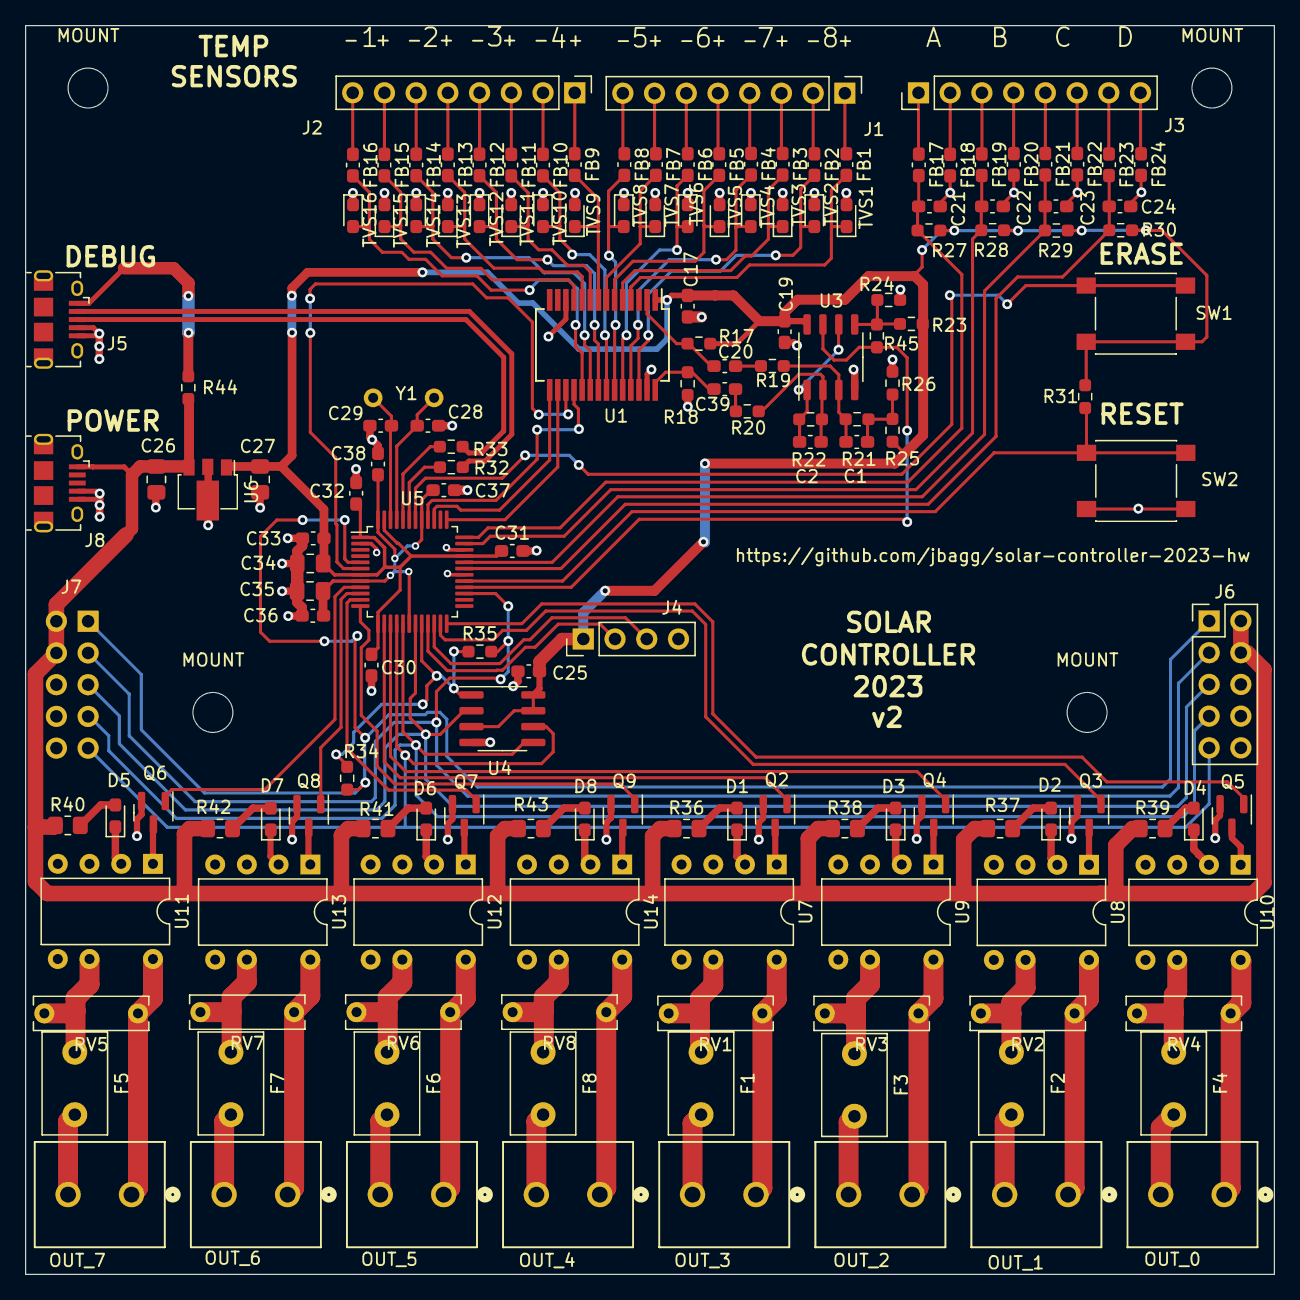
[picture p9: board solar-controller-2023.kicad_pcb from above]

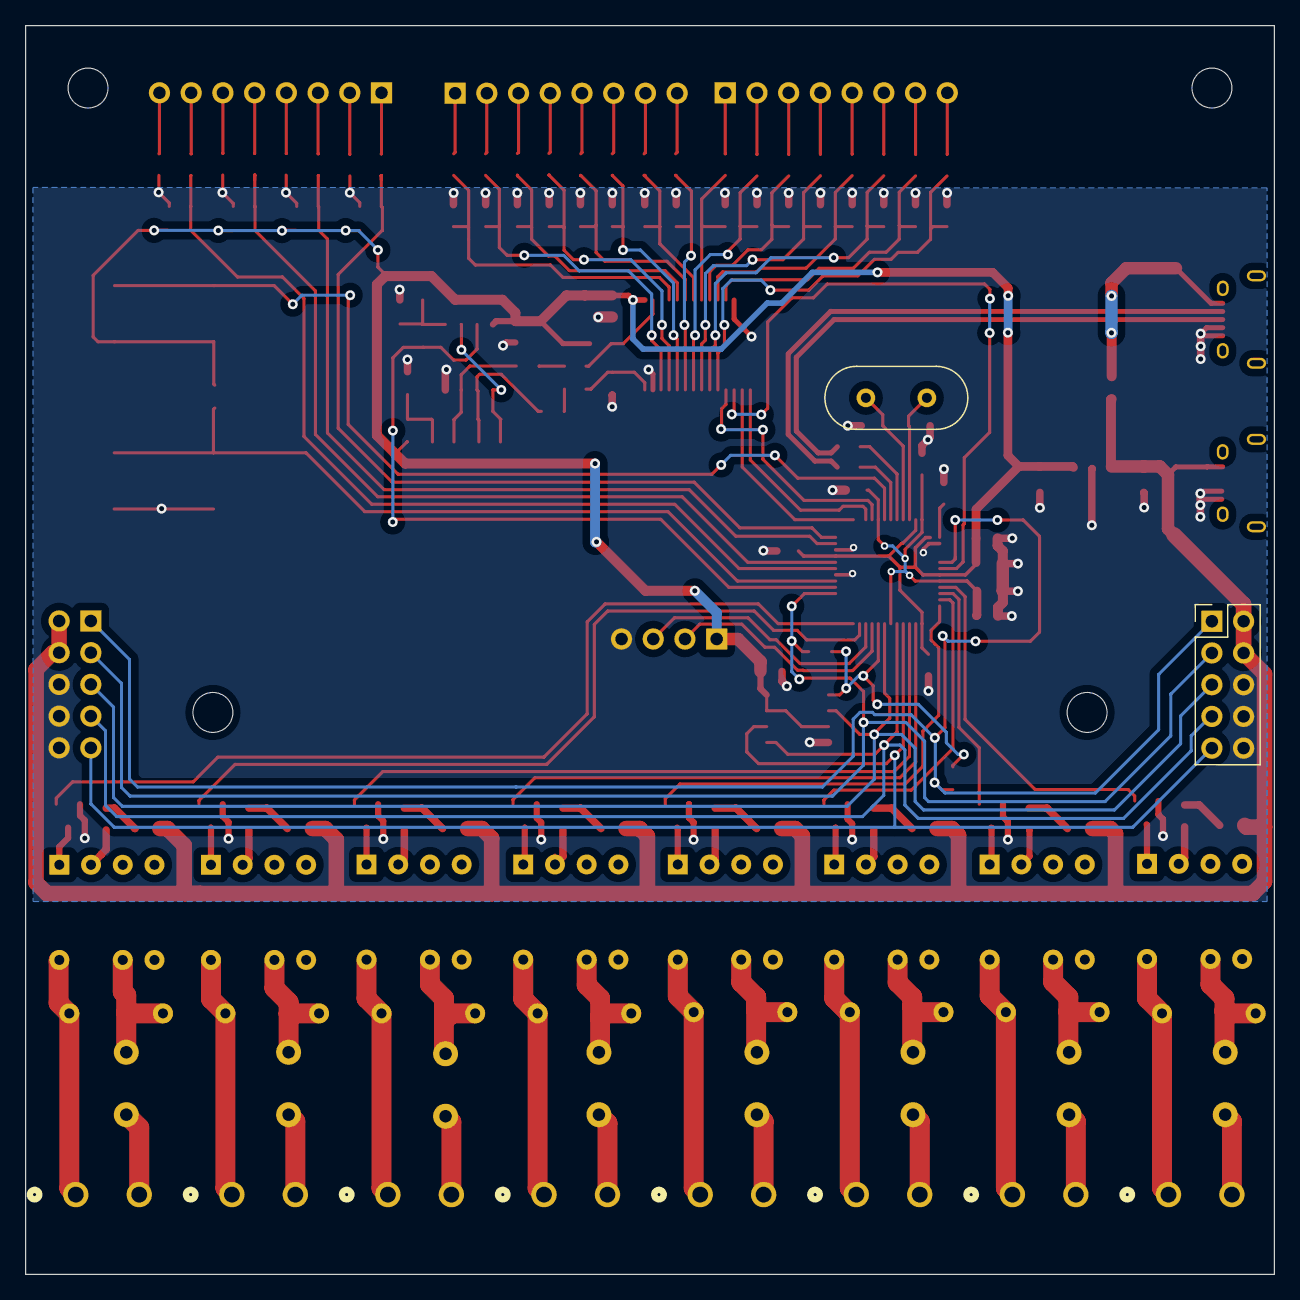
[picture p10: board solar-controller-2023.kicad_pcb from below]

Board: 2 copper layers, 100.0 x 100.0 mm, 161 parts (2 on the bottom side), 135 nets.

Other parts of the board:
MOUNT: MountingHole_3.2mm_M3
MOUNT#2, MOUNT#3, MOUNT#4: MountingHole_3.2mm_M3

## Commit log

2023-10-07 schematic annotated
    [mcu.kicad_sch, outputs.kicad_sch, sensors.kicad_sch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]
2023-10-10 changes for layout
    [mcu.kicad_sch, outputs.kicad_sch, sensors.kicad_sch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]
2023-10-10 add gerbers
    [solar-controller-2023-B_Cu.gbl, solar-controller-2023-B_Mask.gbs, solar-controller-2023-B_Paste.gbp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]
2023-10-11 should have been committed before gerber generation
    [solar-controller-2023.kicad_pcb]
2023-10-11 added some part numbers
    [mcu.kicad_sch, outputs.kicad_sch, sensors.kicad_sch]
2023-11-05 add copyright notices
    [mcu.kicad_sch, outputs.kicad_sch, sensors.kicad_sch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]
2023-11-05 add pdf of schematic
2023-11-06 AC couple LMT01 signal conditioning and add gain
    The difference circuit U3A was DC coupled and so could not
    have gain. Unit gain was only good for sensors up to 15m of
    cat-5.
    [mcu.kicad_sch, outputs.kicad_sch, sensors.kicad_sch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]
2023-11-08 replace sensor wire esd caps with TVSs
    [mcu.kicad_sch, outputs.kicad_sch, sensors.kicad_sch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]
2023-11-15 generate gerbers
    [outputs.kicad_sch, sensors.kicad_sch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]
2023-11-15 add github link to title block and print schematic pdf
    [mcu.kicad_sch, outputs.kicad_sch, sensors.kicad_sch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]
